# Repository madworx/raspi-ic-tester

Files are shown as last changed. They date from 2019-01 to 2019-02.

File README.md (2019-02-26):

# ic-tester

Minimalistic tester for integrated circuits, using Raspberry PI.

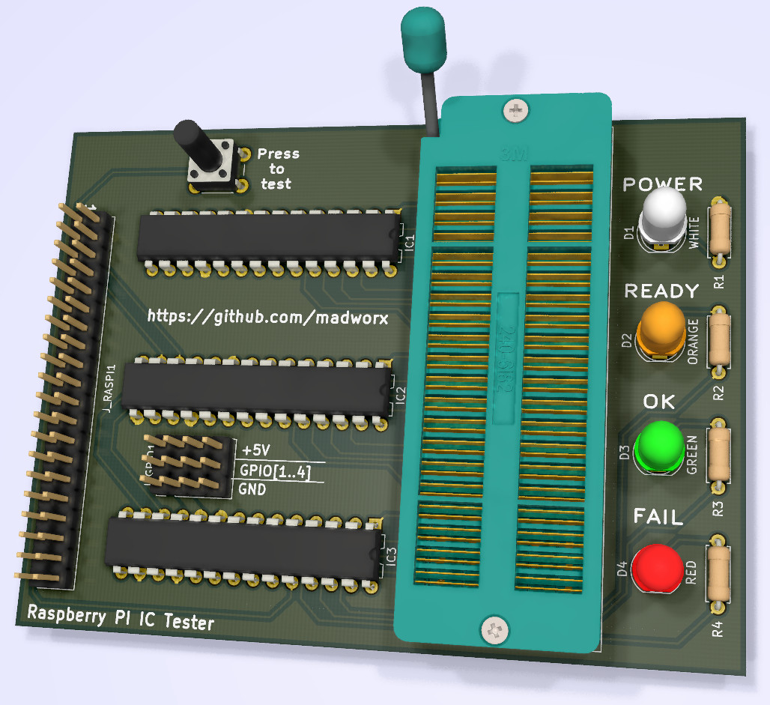
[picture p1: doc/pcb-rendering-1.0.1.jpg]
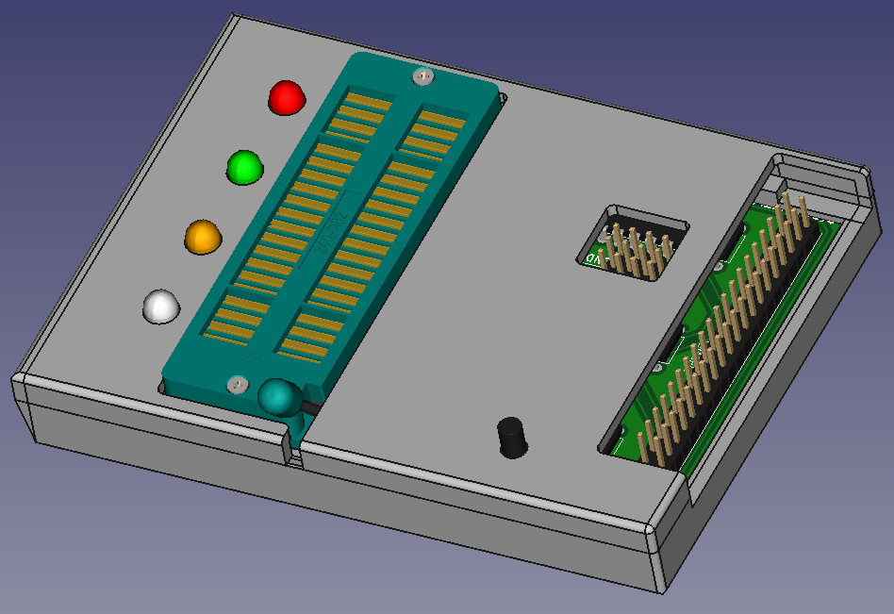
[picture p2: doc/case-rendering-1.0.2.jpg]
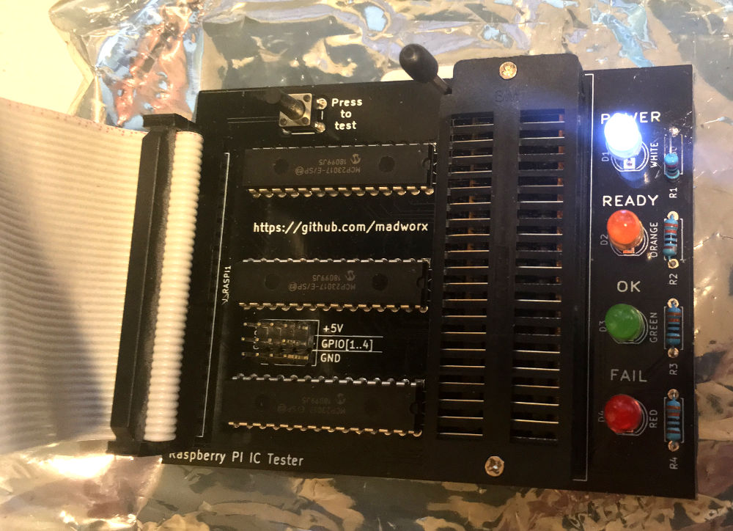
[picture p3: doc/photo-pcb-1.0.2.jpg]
  

## Status

First copy has been build, tested and is working.

Software draft has been written and is working, files in `software/` subdirectory. Run the `raspi-ic-tester.py` script. IC definitions are in `*.md` files.

Case was printed, but tolerances were too low.

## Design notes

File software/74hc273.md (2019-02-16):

# General

| Property | Value |
|---|---|
| NAME | 74(HCT?)?273 |
| DATASHEET | https://assets.nexperia.com/documents/data-sheet/74HC_HCT273.pdf |
| DESCRIPTION | Octal D-type flip-flop with reset; positive-edge trigger |

# Pin definitions

These pin-defintions are valid for the DIP encapsulation.

| Pin |  Name | Direction |
|-----|---|---|
|  1  | ~MR | I |
|  2  | Q0 | O |
|  3  | D0 | I |
|  4  | D1 | I |
|  5  | Q1 | O |
|  6  | Q2 | O |
|  7  | D2 | I |
|  8  | D3 | I |
|  9  | Q3 | O |
| 10  | GND | 0 |
| 11  | CP | I |
| 12  | Q4 | O |
| 13  | D4 | I |
| 14  | D5 | I |
| 15  | Q5 | O |
| 16  | Q6 | O |
| 17  | D6 | I |
| 18  | D7 | I |
| 19  | Q7 | O |
| 20  | VCC | 1 |

# Template

| D | CP | ~MR | Q | Description |
|---|----|-----|---|---|
| 0 | 0  |  0  | x | Initial state - trigger reset. |
| 0 | 1  |  1  | 0 | Raise clock - Q should still be zero. |
| 0 | 0  |  1  | 0 | Lower clock - Q still zero. |
| 1 | 0  |  1  | 0 | Prepare for output high. |
| 1 | 1  |  1  | 1 | Clock output high. |
| 0 | 0  |  1  | 1 | Output should still be high after CLK=0. |
| 0 | 0  |  0  | 0 | Setting CP to 0 should clear output. |

## Test first unit

| Value | Pin  |
|---|---|
| D |  D0  |
| Q |  Q0  |
| CP  |  CP  |
|  ~MR  | ~MR  |

## Test second unit

| Value | Pin  |
|---|---|
| D |  D1  |
| Q |  Q1  |
| CP  |  CP  |
|  ~MR  | ~MR  |

## Test third unit

| Value | Pin  |
|---|---|
| D |  D2  |
| Q |  Q2  |
| CP  |  CP  |
|  ~MR  | ~MR  |

## Test fourth unit

| Value | Pin  |
|---|---|
| D |  D3  |
| Q |  Q3  |
| CP  |  CP  |
|  ~MR  | ~MR  |

## Test fifth unit

| Value | Pin  |
|---|---|
| D |  D4  |
| Q |  Q4  |
| CP  |  CP  |
|  ~MR  | ~MR  |

## Test sixth unit

| Value | Pin  |
|---|---|
| D |  D5  |
| Q |  Q5  |
| CP  |  CP  |
|  ~MR  | ~MR  |

## Test seventh unit

| Value | Pin  |
|---|---|
| D |  D6  |
| Q |  Q6  |
| CP  |  CP  |
|  ~MR  | ~MR  |

## Test eigth unit

| Value | Pin  |
|---|---|
| D |  D7  |
| Q |  Q7  |
| CP  |  CP  |
|  ~MR  | ~MR  |

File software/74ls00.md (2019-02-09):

## General

| Property | Value |
|---|---|
| NAME | 74(LSHC)?00 |
| DATASHEET | http://www.ti.com/lit/ds/symlink/sn74ls00.pdf |
| DESCRIPTION | Quadruple 2-Input Positive-NAND Gates |

## Pin definitions

These pin-defintions are valid for the DIL/DIP encapsulation.

| Pin | Name | Direction |
|-----|---|---|
|  1  | 1A | I |
|  2  | 1B | I |
|  3  | 1Y | O |
|  4  | 2A | I |
|  5  | 2B | I |
|  6  | 2Y | O |
|  7  | GND | 0 |
|  8  | 3Y | O |
|  9  | 3B | I |
| 10  | 3A | I |
| 11  | 4Y | O |
| 12  | 4B | I |
| 13  | 4A | I |
| 14  | VCC | 1 |

## Template

| A | B | Y | Description |
|---|---|---|---|
| 0 | 0 | 1 | ! (A && B) => ! (0 && 0) => 1 |
| 0 | 1 | 1 | ! (A && B) => ! (0 && 1) => 1 |
| 1 | 0 | 1 | ! (A && B) => ! (1 && 0) => 1 |
| 1 | 1 | 0 | ! (A && B) => ! (1 && 1) => 0 |

## Test first unit
 
| Value | Pin |
|---|-----|
| A |  1A |
| B |  1B |
| Y |  1Y |

## Test second unit

| Value | Pin |
|---|-----|
| A |  2A |
| B |  2B |
| Y |  2Y |

## Test third unit

| Value | Pin |
|---|-----|
| A |  3A |
| B |  3B |
| Y |  3Y |

## Test fouth unit

| Value | Pin |
|---|-----|
| A |  4A |
| B |  4B |
| Y |  4Y |

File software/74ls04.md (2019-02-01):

# General

| Property | Value |
|---|---|
| NAME | 74(LSHC)?04 |
| DATASHEET | http://www.ti.com/lit/ds/symlink/sn5404.pdf |
| DESCRIPTION | Hex inverters |

# Pin definitions

These pin-defintions are valid for the DIL/DIP encapsulation.

| Pin | Name | Direction |
|-----|---|---|
|  1  | 1A | I |
|  2  | 1Y | O |
|  3  | 2A | I |
|  4  | 2Y | O |
|  5  | 3A | I |
|  6  | 3Y | O |
|  7  | GND | 0 |
|  8  | 4Y | O |
|  9  | 4A | I |
| 10  | 5Y | O |
| 11  | 5A | I |
| 12  | 6Y | O |
| 13  | 6A | I |
| 14  | VCC | 1 |

# Template

| A | Y | Description |
|---|---|---|
| 1 | 0 | 1 -> 0 |
| 0 | 1 | 0 -> 1 |

# Test first unit
 
| Value | Pin |
|---|-----|
| A |  1A |
| Y |  1Y |

# Test second unit
 
| Value | Pin |
|---|-----|
| A |  1A |
| Y |  1Y |

# Test third unit
 
| Value | Pin |
|---|-----|
| A |  1A |
| Y |  1Y |

# Test fourth unit
 
| Value | Pin |
|---|-----|
| A |  1A |
| Y |  1Y |

# Test fifth unit
 
| Value | Pin |
|---|-----|
| A |  1A |
| Y |  1Y |

# Test sixth unit
 
| Value | Pin |
|---|-----|
| A |  1A |
| Y |  1Y |

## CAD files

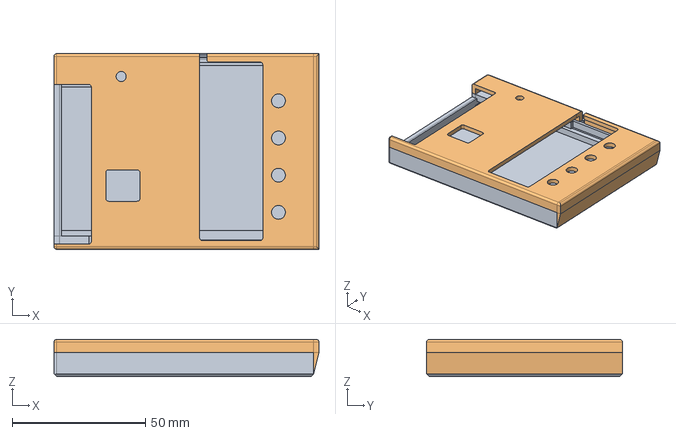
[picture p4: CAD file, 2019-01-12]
case.FCStd
99.5 x 73.5 x 14.0 mm
Case bottom
Case top

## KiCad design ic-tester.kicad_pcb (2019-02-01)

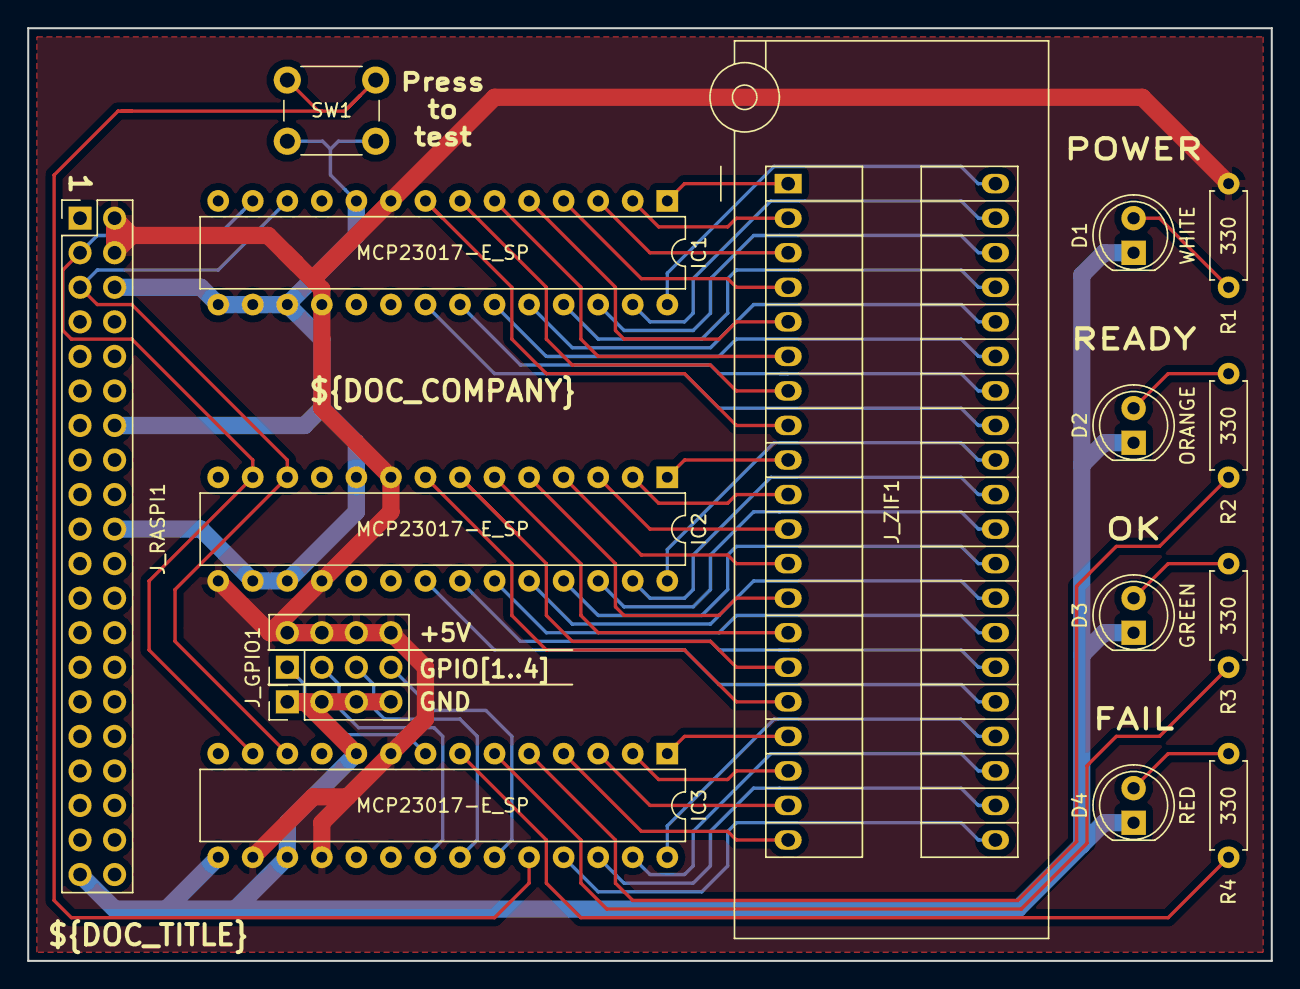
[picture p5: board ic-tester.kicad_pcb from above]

Board: 2 copper layers, 91.4 x 68.6 mm, 16 parts (0 on the bottom side), 56 nets.

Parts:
D1: WHITE; LED_D5.0mm_Clear
D2: ORANGE; LED_D5.0mm
D3: GREEN; LED_D5.0mm
D4: RED; LED_D5.0mm
IC1, IC2, IC3: MCP23017-E_SP; DIP-28_W7.62mm
J1: Conn_01x04; PinHeader_1x04_P2.54mm_Vertical
J_GPIO1: Conn_02x04_Odd_Even; PinHeader_2x04_P2.54mm_Vertical
J_RASPI1: Raspberry_Pi_2_3; PinHeader_2x20_P2.54mm_Vertical
J_ZIF1: Conn_02x20_Counter_Clockwise; 3M_Textool_240-1288-00-0602J_2x20_P2.54mm
R1, R2, R3, R4: 330; R_Axial_DIN0207_L6.3mm_D2.5mm_P7.62mm_Horizontal
SW1: SW_SPST; SW_PUSH_6mm_H13mm

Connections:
/GPIO1: IC3.8, J_GPIO1.1
/GPIO2: IC3.21, J_GPIO1.3
/GPIO3: IC3.22, J_GPIO1.5
/GPIO4: IC3.23, J_GPIO1.7
/LED_FAIL: IC3.7, R4.2
/LED_OK: IC3.6, R3.2
/LED_RDY: IC3.5, R2.2
/SCL: IC1.12, IC2.12, IC3.12, J_RASPI1.5
/SDA: IC1.13, IC2.13, IC3.13, J_RASPI1.3
/SW_TEST: IC3.24, SW1.1
/ZIF01: IC1.1, J_ZIF1.1
/ZIF02: IC1.2, J_ZIF1.2
/ZIF03: IC1.3, J_ZIF1.3
/ZIF04: IC1.4, J_ZIF1.4
/ZIF05: IC1.5, J_ZIF1.5
/ZIF06: IC1.6, J_ZIF1.6
/ZIF07: IC1.7, J_ZIF1.7
/ZIF08: IC1.8, J_ZIF1.8
/ZIF09: IC2.1, J_ZIF1.9
/ZIF10: IC2.2, J_ZIF1.10
/ZIF11: IC2.3, J_ZIF1.11
/ZIF12: IC2.4, J_ZIF1.12
/ZIF13: IC2.5, J_ZIF1.13
/ZIF14: IC2.6, J_ZIF1.14
/ZIF15: IC2.7, J_ZIF1.15
/ZIF16: IC2.8, J_ZIF1.16
/ZIF17: IC3.1, J_ZIF1.17
/ZIF18: IC3.2, J_ZIF1.18
/ZIF19: IC3.3, J_ZIF1.19
/ZIF20: IC3.4, J_ZIF1.20
/ZIF21: IC3.25, J_ZIF1.21
/ZIF22: IC3.26, J_ZIF1.22
/ZIF23: IC3.27, J_ZIF1.23
/ZIF24: IC3.28, J_ZIF1.24
/ZIF25: IC2.21, J_ZIF1.25
/ZIF26: IC2.22, J_ZIF1.26
/ZIF27: IC2.23, J_ZIF1.27
/ZIF28: IC2.24, J_ZIF1.28
/ZIF29: IC2.25, J_ZIF1.29
/ZIF30: IC2.26, J_ZIF1.30
/ZIF31: IC2.27, J_ZIF1.31
/ZIF32: IC2.28, J_ZIF1.32
/ZIF33: IC1.21, J_ZIF1.33
/ZIF34: IC1.22, J_ZIF1.34
/ZIF35: IC1.23, J_ZIF1.35
/ZIF36: IC1.24, J_ZIF1.36
/ZIF37: IC1.25, J_ZIF1.37
/ZIF38: IC1.26, J_ZIF1.38
/ZIF39: IC1.27, J_ZIF1.39
/ZIF40: IC1.28, J_ZIF1.40
GND: D1.1, D2.1, D3.1, D4.1, IC1.10, IC1.15, IC1.16, IC1.17, IC2.10, IC2.16, IC2.17, IC3.10, IC3.15, IC3.17, J1.1, J1.2, J1.3, J1.4, J_RASPI1.6, J_RASPI1.9, J_RASPI1.14, J_RASPI1.20, J_RASPI1.25, J_RASPI1.30, J_RASPI1.34, J_RASPI1.39, SW1.2
unnamed: D1.2, R1.1
unnamed: D2.2, R2.1
unnamed: D3.2, R3.1
unnamed: D4.2, R4.1
VDD: IC1.9, IC1.18, IC2.9, IC2.15, IC2.18, IC3.9, IC3.16, IC3.18, J_GPIO1.2, J_GPIO1.4, J_GPIO1.6, J_GPIO1.8, J_RASPI1.2, J_RASPI1.4, R1.2

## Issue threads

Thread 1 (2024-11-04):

autodetect ICs

heeplr, 2024-11-04:
This is an awesome project!

Have you thought about combining it with something like https://github.com/akshaybaweja/Smart-IC-Tester/ ? It uses a [database](https://github.com/akshaybaweja/Smart-IC-Tester/blob/master/database.txt) of pin-states to autodetect a lot of logic ICs.

It doesn't do actual testing and doesn't use a nice markdown syntax, so it would be nice to be integrated into your framework.

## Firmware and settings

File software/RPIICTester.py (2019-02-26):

# pylint: disable=invalid-name
"""Raspberry PI IC Tester.
Repository: https://github.com/madworx/raspi-ic-tester
"""

import csv
import re
import time

import adafruit_mcp230xx
import board
import busio
import digitalio

class RPIICTester(object):
    """Main class for the Raspiberry PI IC Tester.
    Relies on the 'expander-netlist.csv' file to figure out which
    pins are connected to which pads.
    """
    def __init__(self):
        self._i2c = busio.I2C(board.SCL, board.SDA)
        self._mcps = {}
        self._pins = {}
        self._pindir = {}
        self._load_expander_netlist()

    def _load_expander_netlist(self):
        with open('expander-netlist.csv', 'r') as csvfile:
            mapreader = csv.reader(csvfile, delimiter=';')
            for row in mapreader:
                if len(row) == 3:
                    if row[0] not in self._mcps:
                        self._mcps[row[0]] = adafruit_mcp230xx.MCP23017(
                            self._i2c, address=int(row[0], base=16))
                    self._pins[row[2]] = self._mcps[row[0]].get_pin(
                        self._decode_padname_to_pin(row[1]))
                elif len(row) == 1 and row[0][0] == '#':
                    pass
                else:
                    raise AssertionError("Unable to parse row from netlist file.")

    @staticmethod
    def _decode_padname_to_pin(padname):
        matches = re.match(r'^GP([AB])([0-9])$', padname)
        if matches:
            return (ord(matches.group(1))-65)*8 + int(matches.group(2))
        else:
            raise AssertionError("Could not grok padname [{0}]".format(padname))

    def _get_pin(self, name):
        return self._pins[name]

    def _set_pin_direction(self,pin,direction):
        if pin in self._pindir:
            old_value = self._pindir[pin]
            if old_value == direction:
                return
        if direction == digitalio.Direction.INPUT:
            pin.direction = digitalio.Direction.INPUT
            pin.pull = None
        elif direction == digitalio.Direction.OUTPUT:
            pin.direction = digitalio.Direction.OUTPUT
        self._pindir[pin] = direction

    def zero_all_pins(self):
        """Put all pins into input mode with no pull-up."""
        for pinname in self._pins:
            pin = self._get_pin(pinname)
            self._set_pin_direction(pin,digitalio.Direction.INPUT)

    def read_pin(self, name):
        """Configure the given pin (e.g. "ZIF03") as an input pin,
        and read the value from it."""
        pin = self._get_pin(name)
        self._set_pin_direction(pin,digitalio.Direction.INPUT)
        return pin.value

    def set_pin(self, name, value=True):
        """Configure the given pin (e.g. "ZIF24") as an output pin,
        and set it to the specified value."""
        pin = self._get_pin(name)
        self._set_pin_direction(pin,digitalio.Direction.OUTPUT)
        pin.value = value

    def set_led_ok(self, value=True):
        """Set the "OK" LED"""
        self.set_pin('LED_OK', value)

    def set_led_fail(self, value=True):
        """Set the "FAIL" LED"""
        self.set_pin('LED_FAIL', value)

    def set_led_ready(self, value=True):
        """Set the "READY" LED"""
        self.set_pin('LED_RDY', value)

    def wait_for_press(self):
        """Wait until the "Press to test" button has been pressed"""
        self._get_pin('SW_TEST').pull = digitalio.Pull.UP
        while self.read_pin('SW_TEST'):
            time.sleep(0.05)

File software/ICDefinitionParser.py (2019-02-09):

# pylint: disable=invalid-name
"""Parser of markdown-style IC defintion files"""
from __future__ import print_function
import re

def parse_file(fname):
    """Attempt to parse the given file as a
    markdown IC-definition file."""
    state = None
    sections = {}
    with open(fname, 'r') as content_file:
        content = content_file.read()
        lines = re.split(r'\n', content)
        for line in lines:
            if state is None:
                matches = re.match(r'^##?\s*([^#]+)', line)
                if matches:
                    last_section = matches.group(1)
                    state = 'PARSE_TABLE'
                else:
                    print("Could not grok [{}]".format(line))
            elif state == 'PARSE_TABLE':
                if re.match(r'^[|]', line):
                    state = 'PARSE_TABLE_DATA'
                    table_rows = []
                    table_headers = []
                    for col in line.split("| "):
                        table_headers.append(col.strip(" |"))
                    table_headers = table_headers[1:]
                #else:
                    #print("Ignoring noise [{}]".format(line))
            elif state == 'PARSE_TABLE_DATA':
                if re.match(r'^[|]', line):
                    if not re.match(r'^[|]-', line):
                        row = []
                        for col in line.split("| "):
                            row.append(col.strip(" |"))
                        row = row[1:]
                        table_rows.append(dict(zip(table_headers, row)))
                else:
                    state = None
                    sections[last_section] = table_rows
        return sections

class IC(object):
    """Represents a parsed IC definition."""
    def __init__(self, icdata):
        self.properties = {}
        self.pins = {}
        self.tests = {}
        #print(icdata['General'])
        for icprop in icdata['General']:
            if 'Value' in icprop:
                self.properties[icprop['Property']] = icprop['Value']
        for pins in icdata['Pin definitions']:
            if 'Pin' in pins:
                self.pins[pins['Pin']] = []
                self.pins[pins['Pin']].append(pins['Direction'])
                self.pins[pins['Pin']].append(pins['Name'])
        self.template = icdata['Template']
        tests = [x for x in icdata.keys() if re.match(r'^Test .+', x)]
        for test in tests:
            self.tests[test] = {}
            for testline in icdata[test]:
                if 'Value' in testline:
                    self.tests[test][testline['Pin']] = testline['Value']
        if not self.tests:
            # Generate implicit test from template:
            self.tests['Test template'] = {}
            for tpl in self.template[0]:
                if tpl != 'Description':
                    self.tests['Test template'][tpl] = tpl

    def __repr__(self):
        return self.properties['NAME']

    def get_zif_padname(self, pin):
        """Return the ZIF padname (e.g. "ZIF14") for the given
        pin number for this IC."""
        max_pin = max([int(x) for x in self.pins])
        assert max_pin % 2 == 0
        return "ZIF{0:02d}".format(40-(max_pin-int(pin))
                                   if int(pin) > max_pin/2 else int(pin))

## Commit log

2019-01-02 Initial import.
    [ic-tester.kicad_pcb, ic-tester.sch]
2019-01-09 For production.
    [ic-tester.kicad_pcb, ic-tester.sch]
2019-01-10 Added 3D models for correctly coloured LEDs, as well as ZIF-socket. Reduced reundandant tracks.
    [ic-tester.kicad_pcb]
2019-01-12 Completed PCB case in FreeCAD. Added draft for software part.
    [case.FCStd, ic-tester.kicad_pcb]
2019-02-01 Draft of software for the tester.
    [expander-netlist.csv, ic-tester.kicad_pcb, ic-tester.sch]
2019-02-02 Broke out functionality into separate files/classes. Fixed linting.
    [ICDefinitionParser.py, RPIICTester.py, raspi-ic-tester.py]
2019-02-16 Added test for 74HCT?273 (Octal D-type flip-flop with reset) - shout out to @tnn2 for the chip! All user to specify number of iterations to run.
    [raspi-ic-tester.py]
2019-02-26 Software fixes * Don't set pin direction in hardware unless we need to. * Implement support for externally driven VDD/GND. (In addition i 1/0) * Make "x" actually work for output pins.
    [RPIICTester.py, raspi-ic-tester.py]
